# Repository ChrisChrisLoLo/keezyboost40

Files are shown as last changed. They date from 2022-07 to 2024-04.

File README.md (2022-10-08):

# keezyboost40

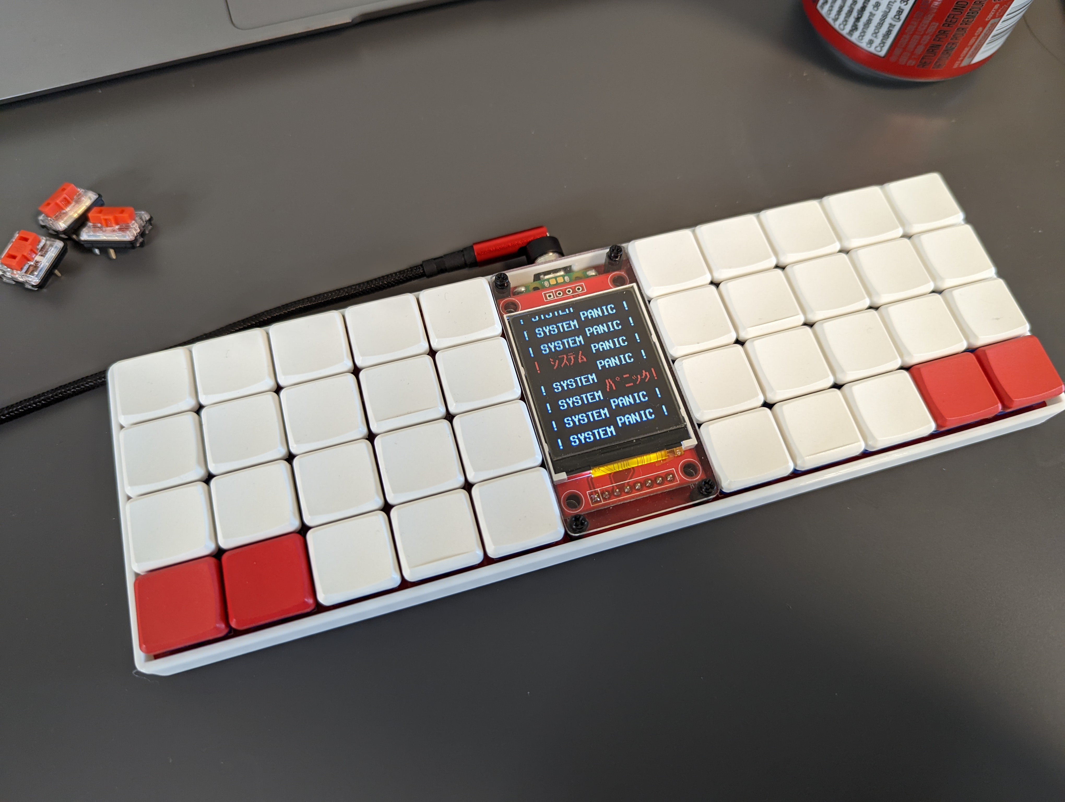
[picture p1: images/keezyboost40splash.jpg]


A 4x10 low profile ortholinear keyboard with an lcd screen in the center. Uses the Raspberry Pi Pico as well as firmware written in Rust (though QMK works too*)

## Features
- Low Profile
    - Keyboard is around 16.5mm thick, keys and keycaps included
- 1.8" LCD Screen
    - Ample real estate for animations, UI, games(?), etc.
- Uses the Raspberry Pi Pico
    - 2MB of flash storage
        - Lots of room for programming with MicroPython, or room for graphics and code
- Parts readily available
    - Only SMD parts required are diodes and kailh choc hotswap sockets
- Supports QMK or Rust firmware
    - QMK hex can be found in firmware file
    - Uses Keyberon as the firmware base, allowing for a "modular" firmware that can easily be built upon
    - More details can be found in DESIGN.md

Display demo here:

keezyboost40 display demo (https://www.youtube.com/watch?v=Bl2fR8NX23E)

## Status
Prototypes are functional, though firmware is still WIP! v0.0 needs a jumper cable from the Pico to the reset pin in the TFT, but works perfectly fine with the Raspberry Pi Pico aside from that. v0.1 fixes this issue (currently in the `master` branch), though hasn't been produced and tested yet.

I need to fix a bug with the animation slowing down, though I suspect it'll mostly involve tinkering with RTOS timings

## PCB
You can generate the gerbers from source in the `pcb` directory, and send off imediately to PCBWay or the like. [PCBWay](https://www.pcbway.com/) has helped sponsor this project, and has provided a fast, easy service while ordering from them. I was also suprised how well my board came out desipte being quite oddly shaped, so I recommend checking them out for your next project!

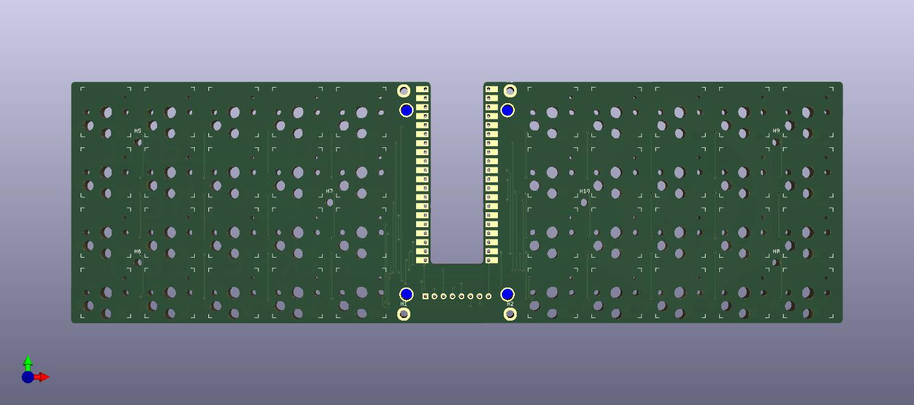
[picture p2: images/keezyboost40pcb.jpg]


## BOM
The following is the materials you will want/need to make your own keezyboost40. Note that anything amount after a `+` denotes the rough amount of spares you may want to have when ordering the parts. Anything involving the acrylic screen is optional. Even the LCD is optional if you prefer more of a lumberjack-y vibe :)
|Part|Count|Notes
|---|---|---|
|PCB|  1| duh|
|Kailh Choc Hotswap Switches| 40+10| |
|LL4148 SMD Diodes|  40+10| This board uses SMD diodes exclusively. I found though-hole diodes often easily slipped around in a way such that the board was no longer able to fit inside the case|
|1.8" ST7735 TFT|  1| Generally speaking, you want the one with the Red PCB. Do NOT use the one from Adafruit, as the pin order on that one is different|
|Raspberry Pi Pico|  1| Try to get the original or a _very_ similar clone with castellated pins. From casual testing, other RP2040 boards may not work (for example, the Pico clones from WeAct can't seem to properly drive the LCD with 3.3V logic)|
|Rubber Feet|  6+2| Any should generally work, though I'm using ~2.5mm thick ones, as they give more space for screw heads, as well as the magnetic connector I'm using|
|3D Printed Case|  1| You could use PCB printing services like PCBWay to make one in resin, though I haven't confirmed if they'd be durable enough to survive in transit|
|M2 Nuts|  10+5| 6 nuts to hold the PCB to the case, and another 4 to hold the acrylic screen to the PCB. I'm using nylon nuts, though any should work. I recommend you grab this with a hex spacer kit, as you get all the M2 parts you need in a single purchase!|
|M2 8mm Double Female spacer|  4+2| Spacers to keep the acrylic from the pcb|
|M2 12mm Screw|  4+2| Screws for the acrylic screen|
|M2 6mm Screw|  6+3| Screws for the PCB and case. Be careful of the size of the screw head! the flatter the better!|
|Acrylic Screen|  1| You can cut one out using the svgs in the `outlines` folder|

## Design
See `DESIGN.md` for small insights about the design choices that went into this board. 

## Directory Structure
- `case`
    You can find the files you need in this folder to print out a case for the keyboard
- `drafts`
    Stores any KLE or intermediate information used in making the case
- `firmware`
    Used to store any firmware relating to the keyboard. Merges to the QMK repo planned.
- `outlines`
    Outlines used for the acrylic screen. Use these to cut your own!
- `pcb`
    Kicad project relating to the project

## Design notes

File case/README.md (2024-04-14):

# Case
Case assembly can be found in `ASSEMBLY.md`.

Case v15 works fairly well, though I may make a newer iteration that makes the Reset button cutout just a tad bit bigger

Case v16 (by Leo Lou) has a larger cutout, which allows for USB-C boards to be used, and it also makes it easier to access the BOOTSEL button.

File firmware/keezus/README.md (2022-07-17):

#   keezus

##  Dependencies
rustup default beta
cargo install flip-link
cargo install probe-run
rustup target add thumbv6m-none-eabi
cargo install elf2uf2-rs

##  Flash Code
Hold the "USB Boot" button (near the QSPI chip), and either press the reset button or re-insert the USB cable to put the board in USB mass-storage bootloader mode.

cargo run --release
##  Troubleshooting
If you get an error such as:

Error: "Memory segment 0x010000->0x010094 is outside of valid address range for device"
Double check that your RUSTFLAGS environment variable, as it will take precedence over the values set in ./cargo/config.toml.

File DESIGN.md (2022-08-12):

# Design

This document outlines some of the design choices I've made with this keyboard, as it is one of my more ambitious designs thus far.

It's a bit more like a rambly blog than anything else.

## Motive and inspiration
I really wanted to play around with low choc profile switches in an ortholinear board, and I wanted to see if the portability of a low profile board would be more convinient than my other current boards.

The three big inspirations (among many others) for this design were the Ghoul, the Technik, the Lumberjack.

The keezyboost40 has the microcontroller in the center, which allows me to fit a microcontroller onto the board without gaining any additional height that would come with, say, soldering the microcontroller under the board.

The acrylic screen and the LCD help make use of the realestate made by having the microcontroller in the center.

## Part choice
I found that generally speaking, the parts I picked generally complemented each other, somewhat by accident. 

I initially picked the rapsberry pi pico over a pro micro due to its lower cost and castelated pins, which I was hoping to use to make the board low profile. However the pico took up considerably more space than the pro-micro. To make use of the real estate, I wanted to do what the Ghoul did, and make use of an LCD screen in the middle. This turned out to be a great compliment, as the large amount of computing power and pins required by the LCD were easily satisfied by the pico. Due to the large amount of pins of the pico, no IO expander or the like is required to have a display _and_ a standard key matrix. This combination of large display and powerful (compared to the ATMega line, at least) microcontroller opens up the door to different kinds of software, UI, and games. I'm excited as this board, on paper, should be capable of doing more things that wasn't previously feasible with a typical OLED and pro-micro. Some ideas I had in mind includes making games or even some sort of tamagotchi program. 

## Firmware design choice
This is arguably where I'm the most torn (and most likely to garner critisism from an online stranger), though this isn't necesarily a one way door either. I needed a firmware that could perform keybaord duties, display to an LCD, as well as be extensible enough that I can comfortably write user programs on top of it. QMK certainly ticks the first box, and thanks to the work of tzarc, writing to a SPI LCD display like mine should be doable with Quantum Painter. My bigger concern with QMK was extensibility (though I'm sure there's some QMK experts who would disagree). To me, I wasn't fully confident that QMK would always have what I need, espectially for something like a tamagotchi game (clocks? interupts? writing to flash? potentially using the pico's second core? There might be a good answer for all of these with QMK, but I didn't like the fact that it feels like I need to / should rely on the constructs and functions that it offers). I could be wrong about most of this QMK stuff, so constructive conversation is welcome.

The biggest appeals to using a Rust based firmware with the keyberon library was the idea that it felt like I was in control of the firmware, and that if there was any problem that I hit with the RP2040 or with the libraries/framework, that I could go into the code and directly fix it myself, rather than having to work in a monolithic structure of sorts. I also like that I could work with a language that has some of the niceities that came with high level languages of the past, as well as a language that can stop me from causing a whole class of bugs. From my limited experience with it, it's a lot more fun programming with it than with C, by a fair margin. Best of all, it's easy to add a library or add a new task to the RTOS if I ever decide to do something esoteric by keyboard standards.

## PCB cutout design choice
For the most part, the PCB is fairly bog-standard. An interesting design choice, of note, however, was the use of having a giant cutout for the pico in the middle of the board. The point of it is so that you can have the pico face down on top of the PCB _and_ be able to access the reset button. It also helps reduce thickness, to a degree by being able to put the pico on top of the PCB rather than at the bottom.

This cut out idea worked well enough in my case, though there's a few caveats that other board builders should be aware of:
- It does somewhat affect board rigdity
    - While completely usable, and not curled up as I initially feared, intentional flexing of the board does concern me a bit.
    - Soldering on a pico helps give board rigidity, though in theory, you're now putting structural strain on the solder joints (!!!) if the board flexes too much
        - Applying generous amounts of solder helps, and having a rigid case prevents this from being a major concern, but I would have fair doubts about putting in in a gasket mount case or without a case
- There's less PCB space
    - hard to fit in fun stuff like buzzers
    - problem is amplified by the size of the pico
- Wrapping traces around the cutout may introduce inductance
    - it's possible that the leads may form a bit of a coil
    - not enough to wreak havoc, though it my be enough to slow/shift keyboard signals enough that adding delays in your firmware become mandatory

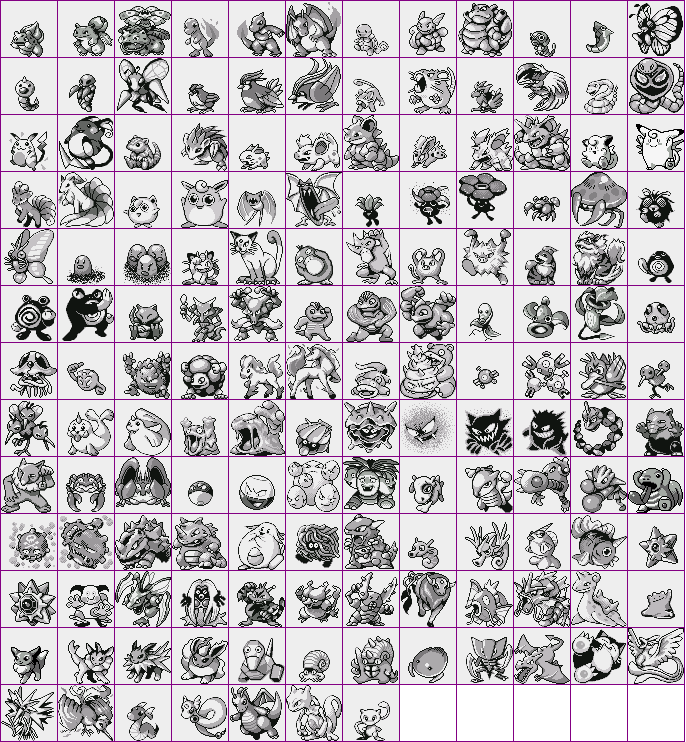
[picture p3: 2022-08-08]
firmware/keezus/assets/1stgen565.bmp

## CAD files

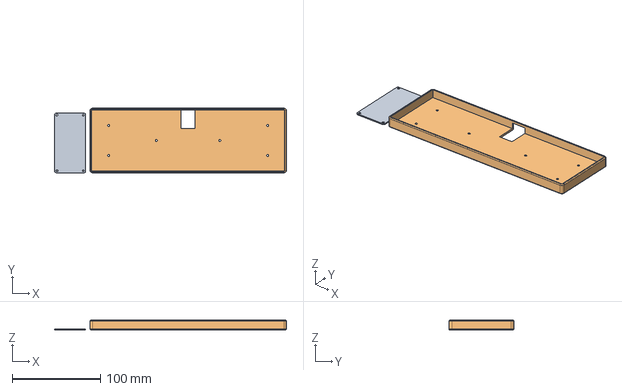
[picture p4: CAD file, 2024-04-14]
case/keezyboost40 v16.step
262.9 x 73.2 x 11.0 mm

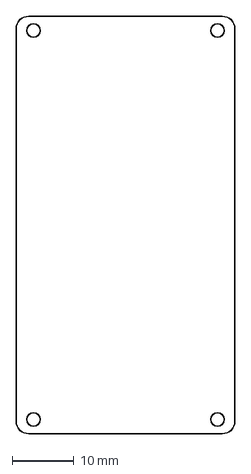
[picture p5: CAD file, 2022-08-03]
outlines/plate_outline.dxf
35.4 x 67.6 mm

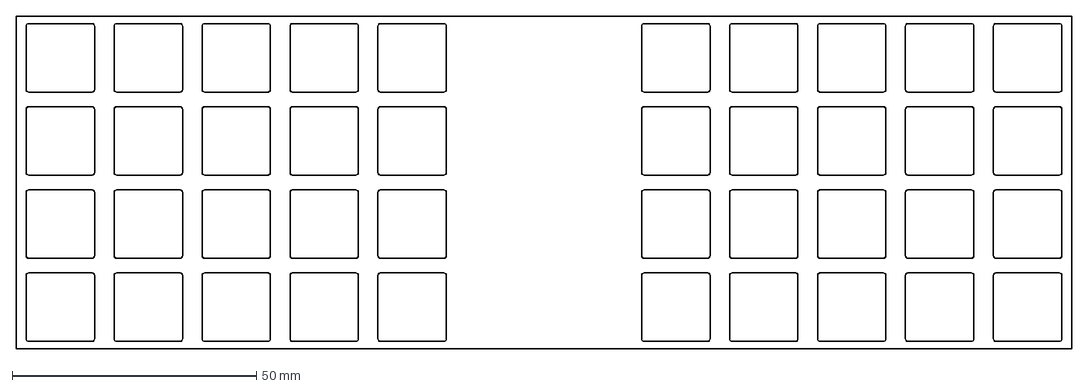
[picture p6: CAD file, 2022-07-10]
outlines/plate-2022-07-10T20 48 17.110Z.dxf
216.0 x 68.0 mm

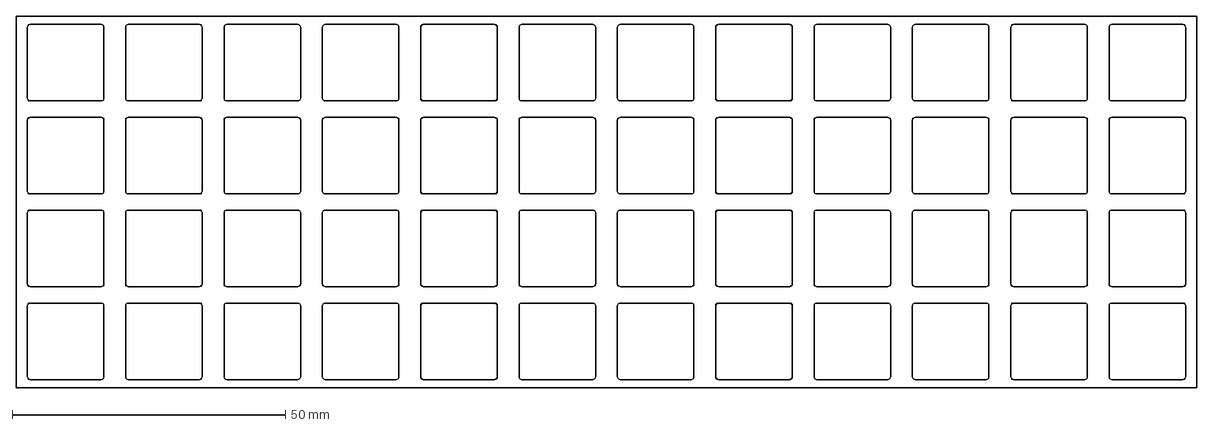
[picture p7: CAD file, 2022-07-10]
outlines/plate-2022-07-09T23 04 02.220Z.dxf
216.0 x 68.0 mm

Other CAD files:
case/keezyboost40 v15.step
case/keezyboost40 v15.stl
case/keezyboost40 v16.stl

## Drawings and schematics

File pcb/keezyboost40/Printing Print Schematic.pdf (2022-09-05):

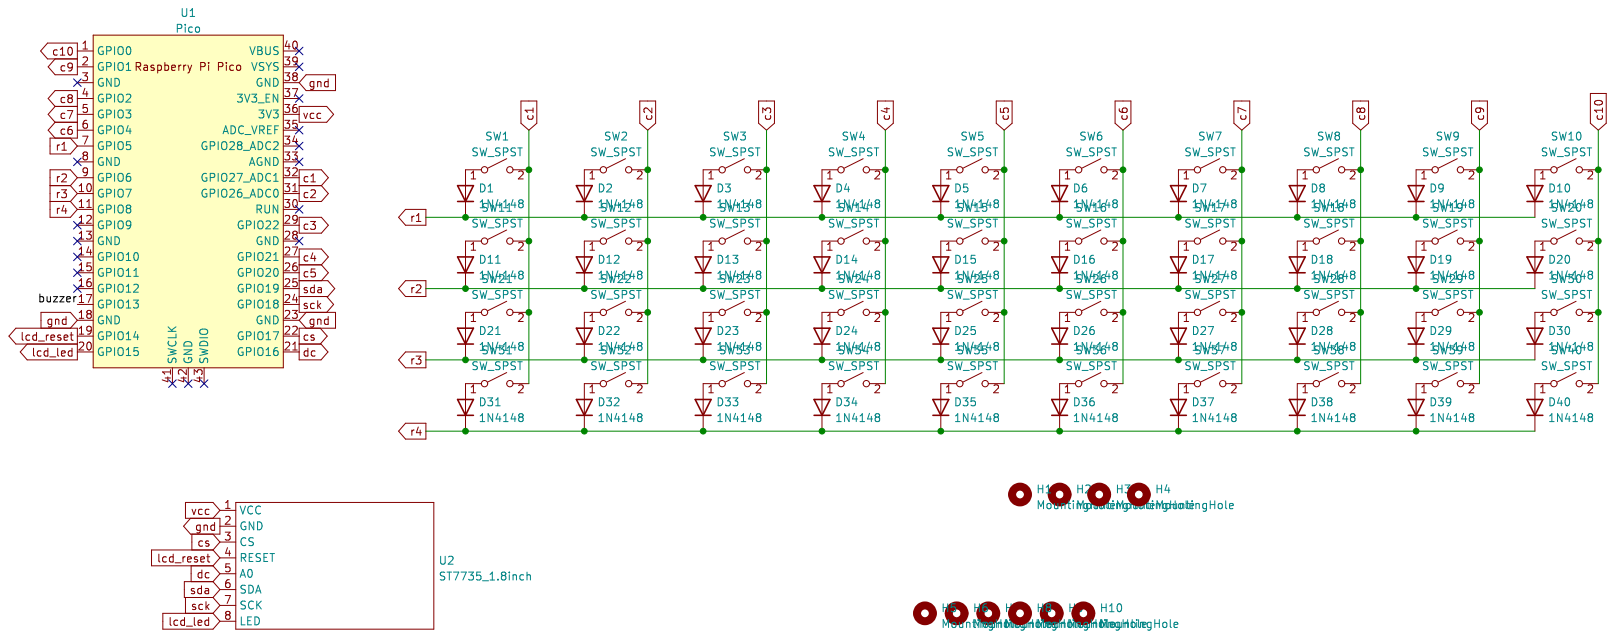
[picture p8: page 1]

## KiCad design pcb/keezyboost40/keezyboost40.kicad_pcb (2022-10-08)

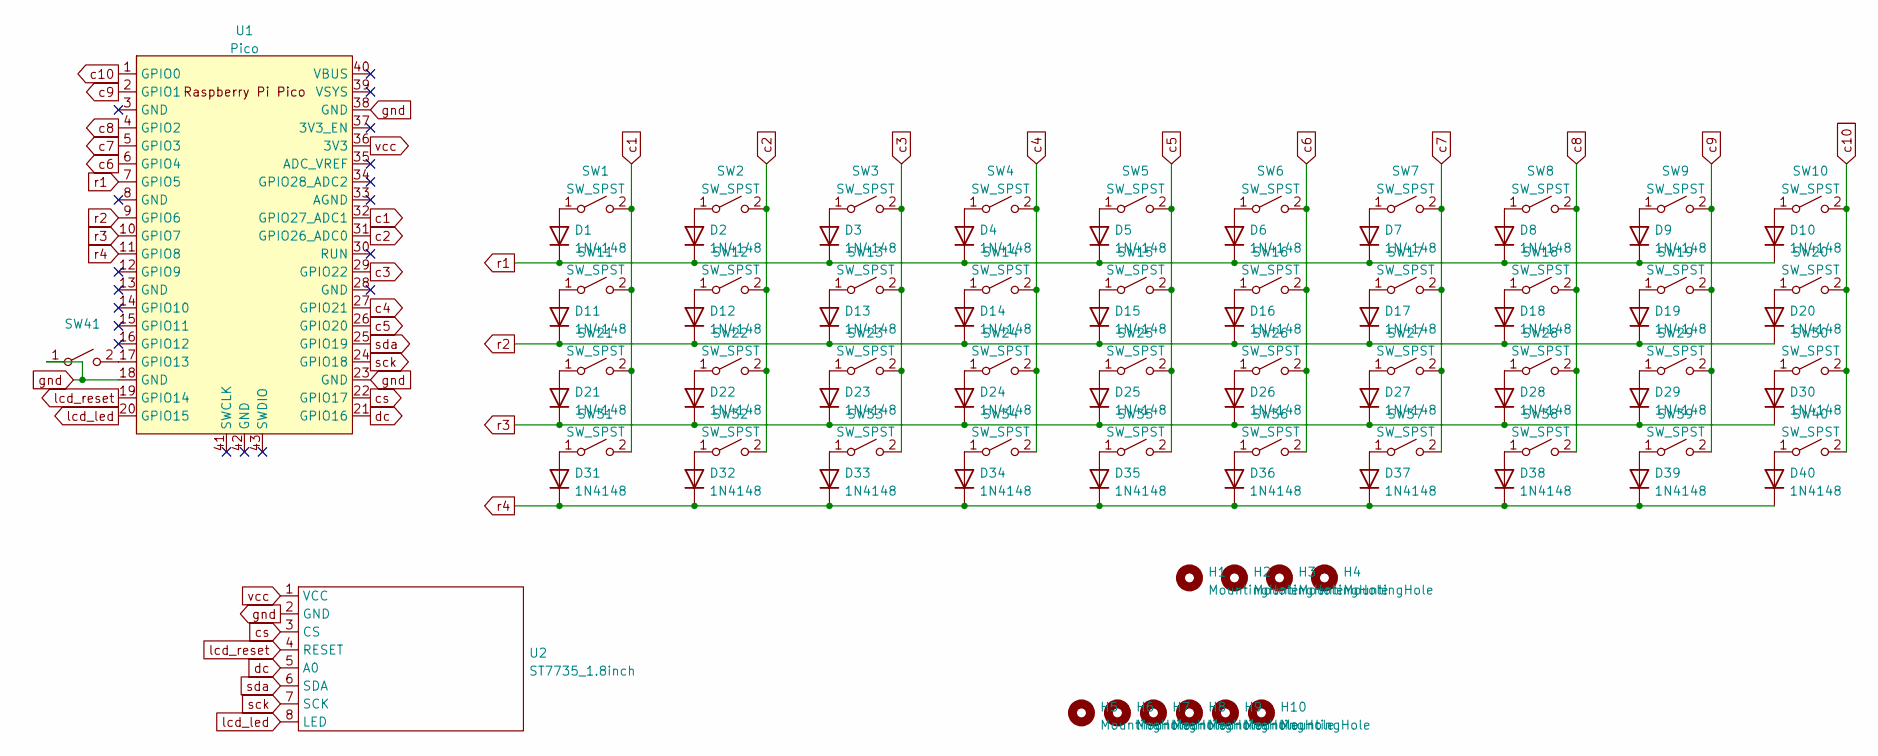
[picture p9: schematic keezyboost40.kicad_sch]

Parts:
D1, D2, D3, D4, D5, D6, D7, D8, D9, D10, D11, D12, D13, D14, D15, D16, D17, D18, D19, D20, D21, D22, D23, D24, D25, D26, D27, D28, D29, D30, D31, D32, D33, D34, D35, D36, D37, D38, D39, D40: 1N4148; D_SOD-123
H1, H2, H3, H4: MountingHole; MountingHole_2.2mm_M2_DIN965_Pad
H5, H6, H7, H8, H9, H10: MountingHole; MountingHole_2.2mm_M2
SW1, SW2, SW3, SW4, SW5, SW6, SW7, SW8, SW9, SW10, SW11, SW12, SW13, SW14, SW15, SW16, SW17, SW18, SW19, SW20, SW21, SW22, SW23, SW24, SW25, SW26, SW27, SW28, SW29, SW30, SW31, SW32, SW33, SW34, SW35, SW36, SW37, SW38, SW39, SW40: SW_SPST; Kailh_socket_PG1350
SW41: (no value)
U1: Pico; RPi_Pico_SMD_TH_OPEN
U2: ST7735_1.8inch

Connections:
unnamed: D1.2 (A), SW1.1 (A)
unnamed: D2.2 (A), SW2.1 (A)
unnamed: D3.2 (A), SW3.1 (A)
unnamed: D4.2 (A), SW4.1 (A)
unnamed: D5.2 (A), SW5.1 (A)
unnamed: D6.2 (A), SW6.1 (A)
unnamed: D7.2 (A), SW7.1 (A)
unnamed: D8.2 (A), SW8.1 (A)
unnamed: D9.2 (A), SW9.1 (A)
unnamed: D10.2 (A), SW10.1 (A)
unnamed: D11.2 (A), SW11.1 (A)
unnamed: D12.2 (A), SW12.1 (A)
unnamed: D13.2 (A), SW13.1 (A)
unnamed: D14.2 (A), SW14.1 (A)
unnamed: D15.2 (A), SW15.1 (A)
unnamed: D16.2 (A), SW16.1 (A)
unnamed: D17.2 (A), SW17.1 (A)
unnamed: D18.2 (A), SW18.1 (A)
unnamed: D19.2 (A), SW19.1 (A)
unnamed: D20.2 (A), SW20.1 (A)
unnamed: D21.2 (A), SW21.1 (A)
unnamed: D22.2 (A), SW22.1 (A)
unnamed: D23.2 (A), SW23.1 (A)
unnamed: D24.2 (A), SW24.1 (A)
unnamed: D25.2 (A), SW25.1 (A)
unnamed: D26.2 (A), SW26.1 (A)
unnamed: D27.2 (A), SW27.1 (A)
unnamed: D28.2 (A), SW28.1 (A)
unnamed: D29.2 (A), SW29.1 (A)
unnamed: D30.2 (A), SW30.1 (A)
unnamed: D31.2 (A), SW31.1 (A)
unnamed: D32.2 (A), SW32.1 (A)
unnamed: D33.2 (A), SW33.1 (A)
unnamed: D34.2 (A), SW34.1 (A)
unnamed: D35.2 (A), SW35.1 (A)
unnamed: D36.2 (A), SW36.1 (A)
unnamed: D37.2 (A), SW37.1 (A)
unnamed: D38.2 (A), SW38.1 (A)
unnamed: D39.2 (A), SW39.1 (A)
unnamed: D40.2 (A), SW40.1 (A)
unnamed: SW41.2 (B), U1.17 (GPIO13)
c1: SW1.2 (B), SW11.2 (B), SW21.2 (B), SW31.2 (B), U1.32 (GPIO27_ADC1)
c2: SW2.2 (B), SW12.2 (B), SW22.2 (B), SW32.2 (B), U1.31 (GPIO26_ADC0)
c3: SW3.2 (B), SW13.2 (B), SW23.2 (B), SW33.2 (B), U1.29 (GPIO22)
c4: SW4.2 (B), SW14.2 (B), SW24.2 (B), SW34.2 (B), U1.27 (GPIO21)
c5: SW5.2 (B), SW15.2 (B), SW25.2 (B), SW35.2 (B), U1.26 (GPIO20)
c6: SW6.2 (B), SW16.2 (B), SW26.2 (B), SW36.2 (B), U1.6 (GPIO4)
c7: SW7.2 (B), SW17.2 (B), SW27.2 (B), SW37.2 (B), U1.5 (GPIO3)
c8: SW8.2 (B), SW18.2 (B), SW28.2 (B), SW38.2 (B), U1.4 (GPIO2)
c9: SW9.2 (B), SW19.2 (B), SW29.2 (B), SW39.2 (B), U1.2 (GPIO1)
c10: SW10.2 (B), SW20.2 (B), SW30.2 (B), SW40.2 (B), U1.1 (GPIO0)
cs: U1.22 (GPIO17), U2.3 (CS)
dc: U1.21 (GPIO16), U2.5 (A0)
gnd: SW41.1 (A), U1.18 (GND), U1.23 (GND), U1.38 (GND), U2.2 (GND)
lcd_led: U1.20 (GPIO15), U2.8 (LED)
lcd_reset: U1.19 (GPIO14), U2.4 (RESET)
r1: D1.1 (K), D2.1 (K), D3.1 (K), D4.1 (K), D5.1 (K), D6.1 (K), D7.1 (K), D8.1 (K), D9.1 (K), D10.1 (K), U1.7 (GPIO5)
r2: D11.1 (K), D12.1 (K), D13.1 (K), D14.1 (K), D15.1 (K), D16.1 (K), D17.1 (K), D18.1 (K), D19.1 (K), D20.1 (K), U1.9 (GPIO6)
r3: D21.1 (K), D22.1 (K), D23.1 (K), D24.1 (K), D25.1 (K), D26.1 (K), D27.1 (K), D28.1 (K), D29.1 (K), D30.1 (K), U1.10 (GPIO7)
r4: D31.1 (K), D32.1 (K), D33.1 (K), D34.1 (K), D35.1 (K), D36.1 (K), D37.1 (K), D38.1 (K), D39.1 (K), D40.1 (K), U1.11 (GPIO8)
sck: U1.24 (GPIO18), U2.7 (SCK)
sda: U1.25 (GPIO19), U2.6 (SDA)
vcc: U1.36 (3V3), U2.1 (VCC)

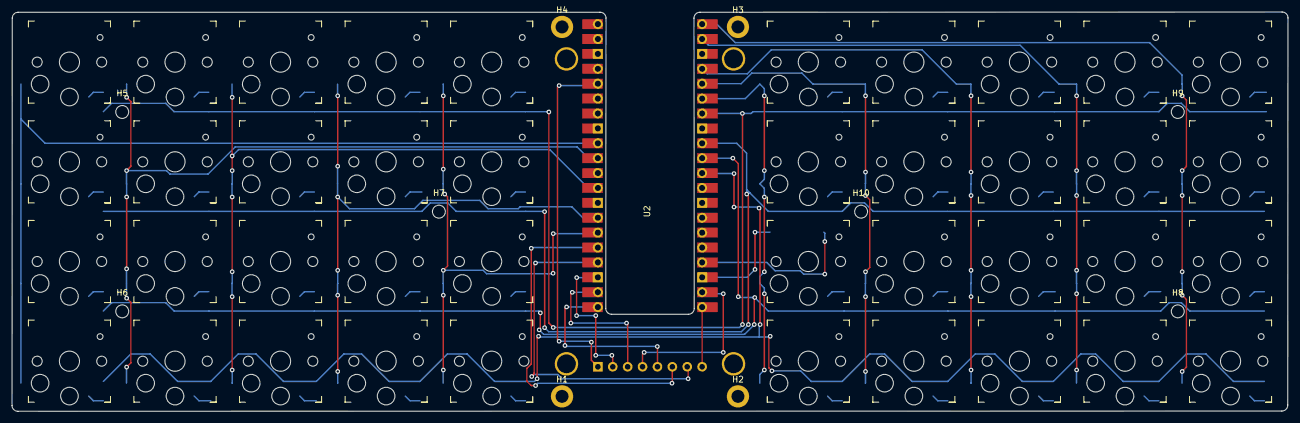
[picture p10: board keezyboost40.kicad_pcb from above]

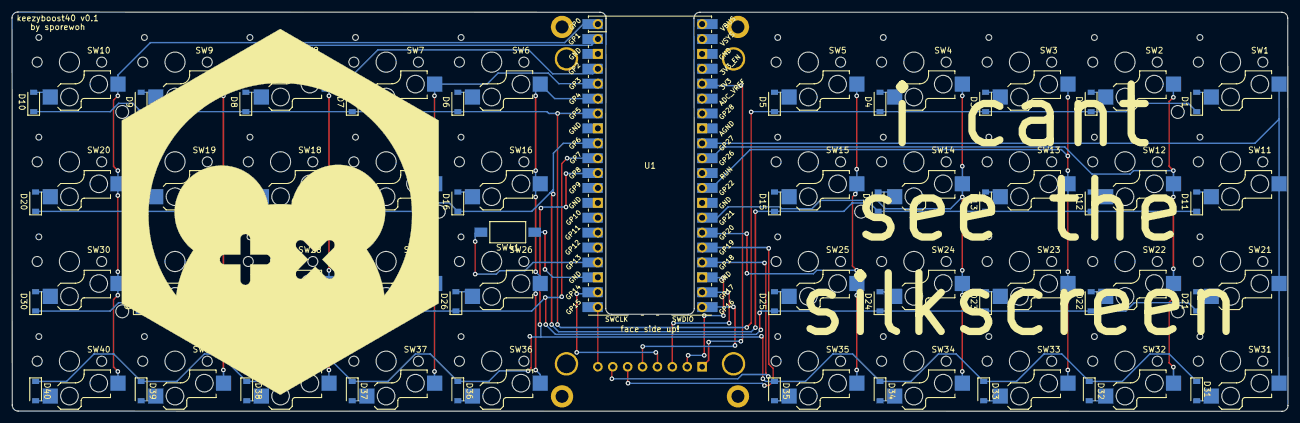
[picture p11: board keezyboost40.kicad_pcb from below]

Board: 2 copper layers, 217.6 x 68.1 mm, 93 parts (42 on the bottom side), 63 nets.

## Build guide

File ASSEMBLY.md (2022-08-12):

# Assembly

This is the assembly doc used to outline the steps used to assemble a keezyboost40. For the most part, it's fairly typical, and a similar build process to the Corne or Reviung.

For now, I will outline steps of interest, and leave best techniques (such as smd diode soldering) as an exercise to the reader due to time constraints in my personal life. Down the road, I may add more fleshed out steps and pictures for a better beginner build experience.

# General Tools
For the best experience, at the minimum, I suggest a decent soldering iron, flux, wire cutters, and a pair of tweezers to hold/move the SMD parts. I use lead-free solder for generally philisophical reasons, though many do claim that using lead solder is easier to work with. Hot air stations are likely very nice too, though I haven't used one personally.

# PCB Assembly
Firstly, solder the diodes onto the board. You want the black bar (cathode) on the diode  to face _down_ for rows 1,2, and 3. For row 4, you will want the diodes to face _up_. This may change in future iterations. Once done I like to wiggle the diodes gently with my tweezers to see if there's any loose connections. Don't be too rough, or you may tear off a pad!

After that, you will want to solder the hotswap sockets on. Don't worry if the solder from the socket touches the solder from the diode: it's positioned in a way where this isn't a problem.

Then, you'll want to solder the Raspberry pico on the board. You'll have to be fairly careful with this step. You want the "front" of the pico to lay down on the "front" PCB such that reset button is facing downwards, and the diodes and sockets are downwards. The pico should also be resting on _top_ of the PCB, so that the PCB sandwich roughly looks like `pico -> PCB -> diodes/sockets`.
From there, solder the pico onto the board using the castelated pins. Using headers with the pico will almost certainly lead to interference with the LCD screen. Solder one corner of the pico to position it, and then an opposite to secure it once the postioning looks good.

Generally speaking, you'll want to test the connections before going further. You'll want to flash the pico with your firmware of choice, and then test all of the keys to confirm that they work. You can do this by shorting the hotswap sockets.

After that, you'll then want to solder on the LCD display. You can keep the pin headers on, though you will need to clip off the SD card with a pair of wire cutters. We do this as the there is no room to utilize the SD card reader, and leaving it on leads to interference. You'll want to clip around the traces of the SD card to free it. Once clipped off, you'll want to tape the entire backside of the display to cover the pokey bits, as well as the conductive bits that could potentially short with the pico below it. After that, put the TFT onto the board and solder the header pins in place. I suggest securing the TFT down with tape or prop it up with a small piece of foam to minimize it moving around during the soldering process.

Once you have soldered that on, you're now done with the PCB!

# Board assembly
The assemly of the case/board is fairly simple.

Assuming you have an acrylic screen, you'll want to make the following "sandwich" with your long 12mm M2 screw:
`screw head -> acrylic piece -> M2 spacer (goes right through it) -> PCB -> M2 nut`. This will effectively secure the acrylic piece to the PCB.

Afterwards, screw the PCB to the case with the following "sandwich":
`screw head -> bottom of case -> PCB -> M2 nut`

Once done, put on your switches and keycaps, and you're done!

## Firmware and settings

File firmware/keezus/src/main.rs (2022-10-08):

#![no_main]
#![no_std]

mod layout;
mod delay;

const NUM_COLS: usize = 10;
const NUM_ROWS: usize = 4;
const NUM_LAYERS: usize = 1;

pub struct Graphics{
    x: i32,
    y: i32,
}  

/// The linker will place this boot block at the start of our program image. We
/// need this to help the ROM bootloader get our code up and running.
#[link_section = ".boot2"]
#[used]
pub static BOOT2: [u8; 256] = rp2040_boot2::BOOT_LOADER_W25Q080;

#[defmt::panic_handler]
fn panic() -> ! {
    cortex_m::asm::udf()
}

#[rtic::app(device = rp2040_hal::pac, peripherals = true, dispatchers = [PIO0_IRQ_0, PIO0_IRQ_1, PIO1_IRQ_0])]
mod app {
    use cortex_m::prelude::{
        _embedded_hal_watchdog_Watchdog, _embedded_hal_watchdog_WatchdogEnable,
    };
    use defmt_rtt as _;
    use embedded_time::duration::Extensions;
    use embedded_time::rate::Extensions as RateExtensions;
    use panic_probe as _;
    use rp2040_hal;
    use rp2040_hal::{
        clocks::{init_clocks_and_plls, Clock},
        gpio::{bank0::*, dynpin::DynPin},
        pac::{I2C0, PIO0, RESETS, SPI0, CorePeripherals},
        pio::{PIOExt, SM0, SM1},
        sio::Sio,
        timer::{Alarm3, Timer, Alarm, Alarm2},
        usb::UsbBus,
        watchdog::Watchdog,
    };
    use embedded_hal::{
        digital::v2::{InputPin, OutputPin},
        timer::CountDown,
    };

    // lcd traits
    use embedded_graphics::image::{Image, ImageRaw, ImageRawLE};
    use embedded_graphics::prelude::*;
    use embedded_graphics::pixelcolor::Rgb565;
    use embedded_graphics::geometry::Point;
    use st7735_lcd;
    use st7735_lcd::Orientation;
    use embedded_time::rate::Hertz;

    use core::iter::once;

    use crate::delay::RP2040TimerDelay;
    use crate::{NUM_COLS, NUM_ROWS, NUM_LAYERS};
    use crate::Graphics;


    use crate::layout as kb_layout;
    use keyberon::debounce::Debouncer;
    use keyberon::key_code;
    use keyberon::layout::{ Event, Layout};

    use usb_device::class::UsbClass;
    use usb_device::class_prelude::UsbBusAllocator;
    use usb_device::device::UsbDeviceState;

    // hardware delay
    // we explicitly do NOT use any delays using SYST as
    // RTIC has already taken it
    use embedded_hal::{prelude::*, watchdog};
    use asm_delay::AsmDelay;
    use asm_delay::bitrate::U32BitrateExt;

    // const SCAN_TIME_US: u32 = 1000;
    const SCAN_TIME_US: u32 = 2000;

    const DISPLAY_UPDATE_TIME_US: u32 = 1700;
    // const DISPLAY_UPDATE_TIME_US: u32 = 3400;

    const EXTERNAL_XTAL_FREQ_HZ: u32 = 12_000_000u32;
    static mut USB_BUS: Option<UsbBusAllocator<UsbBus>> = None;

    const SCREEN_WIDTH: u32 = 128;
    const SCREEN_HEIGHT: u32 = 160;
  
    #[shared]
    struct Shared {
        usb_dev: usb_device::device::UsbDevice<'static, UsbBus>,
        usb_class: keyberon::Class<'static, UsbBus, ()>,
        timer: Timer,
        alarm: Alarm3,
        #[lock_free]
        matrix: keyberon::matrix::Matrix<DynPin,DynPin,NUM_COLS,NUM_ROWS> ,
        layout: Layout<NUM_COLS, NUM_ROWS, NUM_LAYERS, kb_layout::CustomActions>,
        #[lock_free]
        debouncer: Debouncer<[[bool; NUM_COLS]; NUM_ROWS]>,
        #[lock_free]
        watchdog: Watchdog,
        #[lock_free]
        display: st7735_lcd::ST7735<rp2040_hal::Spi<rp2040_hal::spi::Enabled,SPI0,8> , rp2040_hal::gpio::Pin<Gpio16,rp2040_hal::gpio::Output<rp2040_hal::gpio::PushPull>> , rp2040_hal::gpio::Pin<Gpio14,rp2040_hal::gpio::Output<rp2040_hal::gpio::PushPull>>>,
        displayAlarm: Alarm2,
        #[lock_free]
        graphics: Graphics
    }

    #[local]
    struct Local {}


    #[init]
    fn init(c: init::Context) -> (Shared, Local, init::Monotonics) {
        let mut resets = c.device.RESETS;
        let mut watchdog = Watchdog::new(c.device.WATCHDOG);
        watchdog.pause_on_debug(false);

        let clocks = init_clocks_and_plls(
            EXTERNAL_XTAL_FREQ_HZ,
            c.device.XOSC,
            c.device.CLOCKS,
            c.device.PLL_SYS,
            c.device.PLL_USB,
            &mut resets,
            &mut watchdog,
        )
        .ok()
        .unwrap();

        let sio = Sio::new(c.device.SIO);
        let pins = rp2040_hal::gpio::Pins::new(
            c.device.IO_BANK0,
            c.device.PADS_BANK0,
            sio.gpio_bank0,
            &mut resets,
        );

        let mut timer = Timer::new(c.device.TIMER, &mut resets);
        let mut alarm = timer.alarm_3().unwrap();
        let _ = alarm.schedule(SCAN_TIME_US.microseconds());
        alarm.enable_interrupt();
        let mut displayAlarm = timer.alarm_2().unwrap();
        let _ = displayAlarm.schedule(DISPLAY_UPDATE_TIME_US.microseconds());
        displayAlarm.enable_interrupt();


        let (mut pio, sm0, sm1, _, _) = c.device.PIO0.split(&mut resets);

        let usb_bus = UsbBusAllocator::new(UsbBus::new(
            c.device.USBCTRL_REGS,
            c.device.USBCTRL_DPRAM,
            clocks.usb_clock,
            true,
            &mut resets,
        ));

        unsafe {
            USB_BUS = Some(usb_bus);
        }

        let usb_class = keyberon::new_class(unsafe { USB_BUS.as_ref().unwrap() }, ());
        let usb_dev = keyberon::new_device(unsafe { USB_BUS.as_ref().unwrap() });

        let matrix = keyberon::matrix::Matrix::new(
            [
                pins.gpio27.into_pull_up_input().into(),
                pins.gpio26.into_pull_up_input().into(),
                pins.gpio22.into_pull_up_input().into(),
                pins.gpio21.into_pull_up_input().into(),
                pins.gpio20.into_pull_up_input().into(),
                pins.gpio4.into_pull_up_input().into(),
                pins.gpio3.into_pull_up_input().into(),
                pins.gpio2.into_pull_up_input().into(),
                pins.gpio1.into_pull_up_input().into(),
                pins.gpio0.into_pull_up_input().into(),
            ],
            [
                pins.gpio5.into_push_pull_output().into(),
                pins.gpio6.into_push_pull_output().into(),
                pins.gpio7.into_push_pull_output().into(),
                pins.gpio8.into_push_pull_output().into(),
            ],
        );
        // let matrix = keyberon::matrix::Matrix::new(
        //     [
        //         pins.gpio27.into_push_pull_output().into(),
        //         pins.gpio26.into_push_pull_output().into(),
        //         pins.gpio22.into_push_pull_output().into(),
        //         pins.gpio21.into_push_pull_output().into(),
        //         pins.gpio20.into_push_pull_output().into(),
        //         pins.gpio4.into_push_pull_output().into(),
        //         pins.gpio3.into_push_pull_output().into(),
        //         pins.gpio2.into_push_pull_output().into(),
        //         pins.gpio1.into_push_pull_output().into(),
        //         pins.gpio0.into_push_pull_output().into(),
        //     ],
        //     [
        //         pins.gpio5.into_pull_down_input().into(),
        //         pins.gpio6.into_pull_down_input().into(),
        //         pins.gpio7.into_pull_down_input().into(),
        //         pins.gpio8.into_pull_down_input().into(),
        //     ],
        // );


        // These are implicitly used by the spi driver if they are in the correct mode
        let _spi_sclk = pins.gpio18.into_mode::<rp2040_hal::gpio::FunctionSpi>();
        let _spi_mosi = pins.gpio19.into_mode::<rp2040_hal::gpio::FunctionSpi>();
        //let _spi_miso = pins.gpio4.into_mode::<rp2040_hal::gpio::FunctionSpi>();
        let spi = rp2040_hal::Spi::<_, _, 8>::new(c.device.SPI0);

        let mut lcd_led = pins.gpio15.into_push_pull_output();
        let dc = pins.gpio16.into_push_pull_output();
        let rst = pins.gpio14.into_push_pull_output();

        // Exchange the uninitialised SPI driver for an initialised one
        let spi = spi.init(
            &mut resets,
            clocks.peripheral_clock.freq(),
            Hertz::new(16_000_000u32),
            &embedded_hal::spi::MODE_0,
        );

        let mut display = st7735_lcd::ST7735::new(spi, dc, rst, true, false, SCREEN_WIDTH, SCREEN_HEIGHT);
        

        // Cannot use SYST as RTIC has already taken this
        // https://github.com/rtic-rs/cortex-m-rtic/issues/523

        let mut delay = RP2040TimerDelay::new(&timer);
        // let mut delay = cortex_m::delay::Delay::new(core.SYST, clocks.system_clock.freq().0);
        

        // This WORKS
        // use cortex_m::asm::delay;
        // cortex_m::asm::delay(10000000_u32);
        // lcd_led.set_high().unwrap();


        // delay.delay_ms(1000_u32);
        // lcd_led.set_high().unwrap();

        display.init(&mut delay).unwrap();
        display.set_orientation(&Orientation::PortraitSwapped).unwrap();
        display.clear(Rgb565::BLACK).unwrap();
        display.set_offset(0, 0);

        // let image_raw: ImageRawLE<Rgb565> =
        //     ImageRaw::new(include_bytes!("../assets/ferris.raw"), 86);

        // let image: Image<_> = Image::new(&image_raw, Point::new(24, 28));

        // image.draw(&mut display).unwrap();
        
        // Wait until the background and image have been rendered otherwise
        // the screen will show random pixels for a brief moment

        lcd_led.set_high().unwrap();

        // start watchdog after initialization
        // It needs to be fairly high though to account for screen drawing etc
        // watchdog.start(10_000.microseconds());
        watchdog.start(1_000_000.microseconds());


        (
            Shared {
                usb_dev,
                usb_class,
                timer,
                alarm,
                matrix: matrix.unwrap(),
                debouncer: Debouncer::new([[false; NUM_COLS]; NUM_ROWS], [[false; NUM_COLS]; NUM_ROWS], 10),
                layout: Layout::new(&kb_layout::LAYERS),
                watchdog,
                display,
                displayAlarm,
                graphics: crate::Graphics{x:0,y:0}
            },
            Local {},
            init::Monotonics(),
        )
    }

    #[task(binds = USBCTRL_IRQ, priority = 4, shared = [usb_dev, usb_class])]
    fn usb_rx(c: usb_rx::Context) {
        let usb = c.shared.usb_dev;
        let kb = c.shared.usb_class;
        (usb, kb).lock(|usb, kb| {
            if usb.poll(&mut [kb]) {
                kb.poll();
            }
        });
    }

    #[task(priority = 2, capacity = 8, shared = [usb_dev, usb_class, layout])]
    fn handle_event(mut c: handle_event::Context, event: Option<Event>) {
        let mut layout = c.shared.layout;
        match event {
            None => {
                if let keyberon::layout::CustomEvent::Press(event) = layout.lock(|l| l.tick()) {
                    match event {
                        kb_layout::CustomActions::Bootloader => {
                            rp2040_hal::rom_data::reset_to_usb_boot(0, 0);
                        }
                    };
                }
            }
            Some(e) => {
                layout.lock(|l| l.event(e));
                return;
            }
        }       

        let report: key_code::KbHidReport = layout.lock(|l| l.keycodes().collect());
        if !c
            .shared  
            .usb_class
            .lock(|k| k.device_mut().set_keyboard_report(report.clone()))
        {
            return;
        }
        if c.shared.usb_dev.lock(|d| d.state()) != UsbDeviceState::Configured {
            return;
        }
        while let Ok(0) = c.shared.usb_class.lock(|k| k.write(report.as_bytes())) {}
    }

    #[task(binds = TIMER_IRQ_2, priority = 1, shared = [ display, displayAlarm, graphics ])]
    fn screen_update_irq(c: screen_update_irq::Context) {
        // please ignore some of this sloppy code
        // i am a good coder irl i pinky promise

        let mut alarm = c.shared.displayAlarm;

        let display = c.shared.display;
        let graphics = c.shared.graphics;

        let image_raw: ImageRawLE<Rgb565> =
        ImageRaw::new(include_bytes!("../assets/ferris.raw"), 86);

        let image: Image<_> = Image::new(&image_raw, Point::new(0, graphics.y));
        
        //display.clear(Rgb565::BLACK).unwrap();

        //let style = embedded_graphics::mono_font::MonoTextStyle::new(, Rgb565::WHITE);
        let styleBlack = embedded_graphics::mono_font::MonoTextStyle::new(&embedded_graphics::mono_font::ascii::FONT_8X13_BOLD, Rgb565::BLACK);

        let textStyleWhite = embedded_graphics::mono_font::MonoTextStyleBuilder::new()
            .font(&embedded_graphics::mono_font::ascii::FONT_8X13_BOLD)
            .text_color(Rgb565::WHITE)
            .background_color(Rgb565::BLACK)
            .build();
        let textStyleRed = embedded_graphics::mono_font::MonoTextStyleBuilder::new()
            .font(&embedded_graphics::mono_font::jis_x0201::FONT_10X20)
            .text_color(Rgb565::RED)
            .background_color(Rgb565::BLACK)
            .build();

        let FONT_BUFFER = 13;
        // let NUM_LINES = 9;
        let NUM_LINES = 8;
        let TOTAL_HEIGHT = SCREEN_HEIGHT as i32+FONT_BUFFER;

        //embedded_graphics::text::Text::new("Hello Rust!", Point::new(20, graphics.y-1), styleBlack).draw(display);
        for i in 0..NUM_LINES {
            //graphics.y += (( i/NUM_LINES) * 200);
            let newY = (graphics.y+(((SCREEN_HEIGHT as i32+FONT_BUFFER)/(NUM_LINES))*i))%(SCREEN_HEIGHT as i32+FONT_BUFFER);// %(SCREEN_HEIGHT as i32+FONT_BUFFER);
            let style = if i == 0 {textStyleRed} else {textStyleWhite};
            //let text1 = if i == 0 {"! 「システム"} else {"! SYSTEM"}; 
            let text1 = if i == 0 {"! ｼｽﾃﾑ"} else {"! SYSTEM"}; 
            //let text2 = if i == 0 {"パニック」!"} else {"PANIC !"};
            let text2 = if i == 0 {"ﾊﾟﾆｯｸ!"} else {"PANIC !"};
            // let text = if i%2==0 {"hocus"} else {"pocus"};
            embedded_graphics::text::Text::new(text1, Point::new(0, TOTAL_HEIGHT-newY), style).draw(display);
            embedded_graphics::text::Text::new(text2, Point::new(70, newY), style).draw(display);
        }

        
        graphics.y = (graphics.y + 1)%(SCREEN_HEIGHT as i32+FONT_BUFFER);

        //image.draw(display).unwrap();

        alarm.lock(|a| {
            a.clear_interrupt();
            let _ = a.schedule(DISPLAY_UPDATE_TIME_US.microseconds());
        });

    }


    #[task(binds = TIMER_IRQ_3, priority = 2, shared = [ matrix, debouncer, timer, alarm, watchdog, usb_dev, usb_class])]
    fn scan_timer_irq(mut c: scan_timer_irq::Context) {


        c.shared.watchdog.feed();

        for event in c.shared.debouncer.events(c.shared.matrix.get().unwrap()) {
            handle_event::spawn(Some(event)).unwrap();
        }

        handle_event::spawn(None).unwrap();

        let mut alarm = c.shared.alarm;

        alarm.lock(|a| {
            a.clear_interrupt();
            let _ = a.schedule(SCAN_TIME_US.microseconds());
        });
    }
}

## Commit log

2022-07-10 add initial tft lcd footprint
    [keezyboost40.kicad_pcb, keezyboost40.kicad_sch, plate-2022-07-09T23 04 02.220Z.dxf]
2022-07-10 update outlines
    [plate-2022-07-10T20 48 17.110Z.dxf]
2022-07-12 finish v0.0
    [keezyboost40.kicad_pcb, keezyboost40.kicad_sch]
2022-07-15 create gerbers
    [keezyboost40-B_Cu.gbr, keezyboost40-B_Mask.gbr, keezyboost40-B_Paste.gbr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]
2022-07-16 fixup issues with lcd interface connections
    [keezyboost40-B_Cu.gbl, keezyboost40-B_Mask.gbs, keezyboost40-B_SilkS.gbo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]
2022-07-17 init commit for rust firmware
    [keezyboost40.kicad_pcb]
2022-07-23 make lcd use 3.3v over 5v
    [keezyboost40-B_Cu.gbr, keezyboost40-B_Mask.gbr, keezyboost40-B_Paste.gbr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]
2022-08-03 add sheild outlines
    [plate_outline.dxf]
2022-08-07 update interrupts
2022-08-07 Fix screen display by moving watchdog initialization to the end (BAD DOG >:()
    [main.rs]
2022-08-08 fix "ghosting" issue: pull from local fork
    [main.rs, main_old.rs]
2022-08-12 add case files
    [keezyboost40 v15.step, keezyboost40 v15.stl]
2022-08-21 update sponsor info and change 6mm spacer to 8mm spacer
2022-10-08 add reset button
    [keezyboost40-B_Cu.gbr, keezyboost40-B_Mask.gbr, keezyboost40-B_Paste.gbr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]
2024-04-13 Add a case with a bigger cutout
    [keezyboost40 v16.step, keezyboost40 v16.stl]
